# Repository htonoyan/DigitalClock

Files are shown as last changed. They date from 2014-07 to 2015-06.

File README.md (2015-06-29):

#Digital Clock
The "Hello World" project of any electrical engineer, a digital clock. This is a basic ATMegax8 design with the addition of linear constant current shift register sinks to switch low-power 7-segment LED displays that may need a voltage higher than the microcontroller supply voltage to work (I'm using 12V here).

You can read more about the project on my blog: http://htonoyan.blogspot.com. For any questions feel free to contact me by email or posting on the blog.

* Hardware/ Contains all the circuit board files (Altium Designer format, but a PDF version and gerbers are provided).
* Software/ Contains the code running on the AVR ATMega48. I used Atmel Studio with gcc to compile the code.

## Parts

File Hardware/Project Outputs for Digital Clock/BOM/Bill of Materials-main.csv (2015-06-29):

Designator | Supplier Part Number 1 | Description | Footprint | Quantity
BT1 | BU2032SM-HD-GDKR-ND | HOLDER COIN CELL 2032 SMD | BU2032SM-HD-G | 1
C1, C2 | 490-1403-1-ND | CAP CER 10PF 50V 5% C0G 0603 | 0603 | 2
C3, C5, C6, C9, C10 | 445-1316-1-ND | CAP CER .10UF 25V X7R 10% 0603 | 0603 | 5
C7, C8 | 338-1807-1-ND | CAP ALUM 220UF 25V 20% SMD | CAP AVE227M25F24T-F | 2
D1, D2 | 497-8030-6-ND | DIODE SCHOTTKY 30V 2A SMB | DSO-C2/X2.3 | 2
J1 | CP-036APJCT-ND | CONN PWR JACK 2.0X6.3MM SMT | CONN_PWR2.0_SMT | 1
J2, J3, J4, J5, J6, J7, J8, J9 | A19432-ND | CONN HEADER VERT 5POS .100 TIN | CONN_HDR1X5 | 8
P1 | WM17449-ND | Header, 3-Pin, Dual row | CONN_HDR_SMT_6_2R | 1
R1 | P4.70KHCT-ND | RES 4.70K OHM 1/10W 1% 0603 SMD | 0603 | 1
R2, R5 | P1.60KHDKR-ND | RES 1.60K OHM 1/10W 1% 0603 SMD | 0603 | 2
R3 | P698KHDKR-ND | RES 698K OHM 1/10W 1% 0603 SMD | 0603 | 1
R4 | P107KHCT-ND | RES 107K OHM 1/10W 1% 0603 SMD | 0603 | 1
S1, S2, S3, S4 | 506-1571634-2 | Single-Pole, Single-Throw Switch | 1571634-2 | 4
U1 | ATMEGA48V-10AU-ND | IC AVR MCU 4K 10MHZ 1.8V 32TQFP | 32A_N | 1
U2 | NCP1117DT33RKGOSCT-ND | IC REG LDO 3.3V DPAK | DPAK | 1
U3, U4 | 296-23916-1-ND | IC LED DRIVER LINEAR 24-QSOP | SOP24 | 2
U5 | TC1047AVNBCT-ND | IC TEMP-VOLT CONV PREC SOT-23B | SOT23-3N | 1
Y1 | 535-10241-1-ND | CRYSTAL 32.768 KHZ 6.0 PF SMD | ABS25 | 1

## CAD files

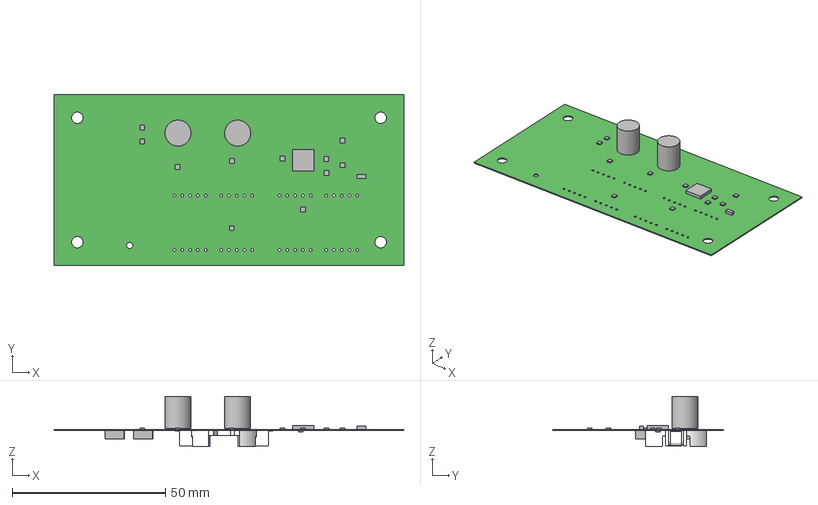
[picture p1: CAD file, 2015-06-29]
Hardware/Project Outputs for Digital Clock/ExportSTEP/PCB1_holes.step
114.3 x 55.9 x 16.5 mm
Board
Extruded x 18
BU2032SM-HD-GCR2032_Battery_Holder

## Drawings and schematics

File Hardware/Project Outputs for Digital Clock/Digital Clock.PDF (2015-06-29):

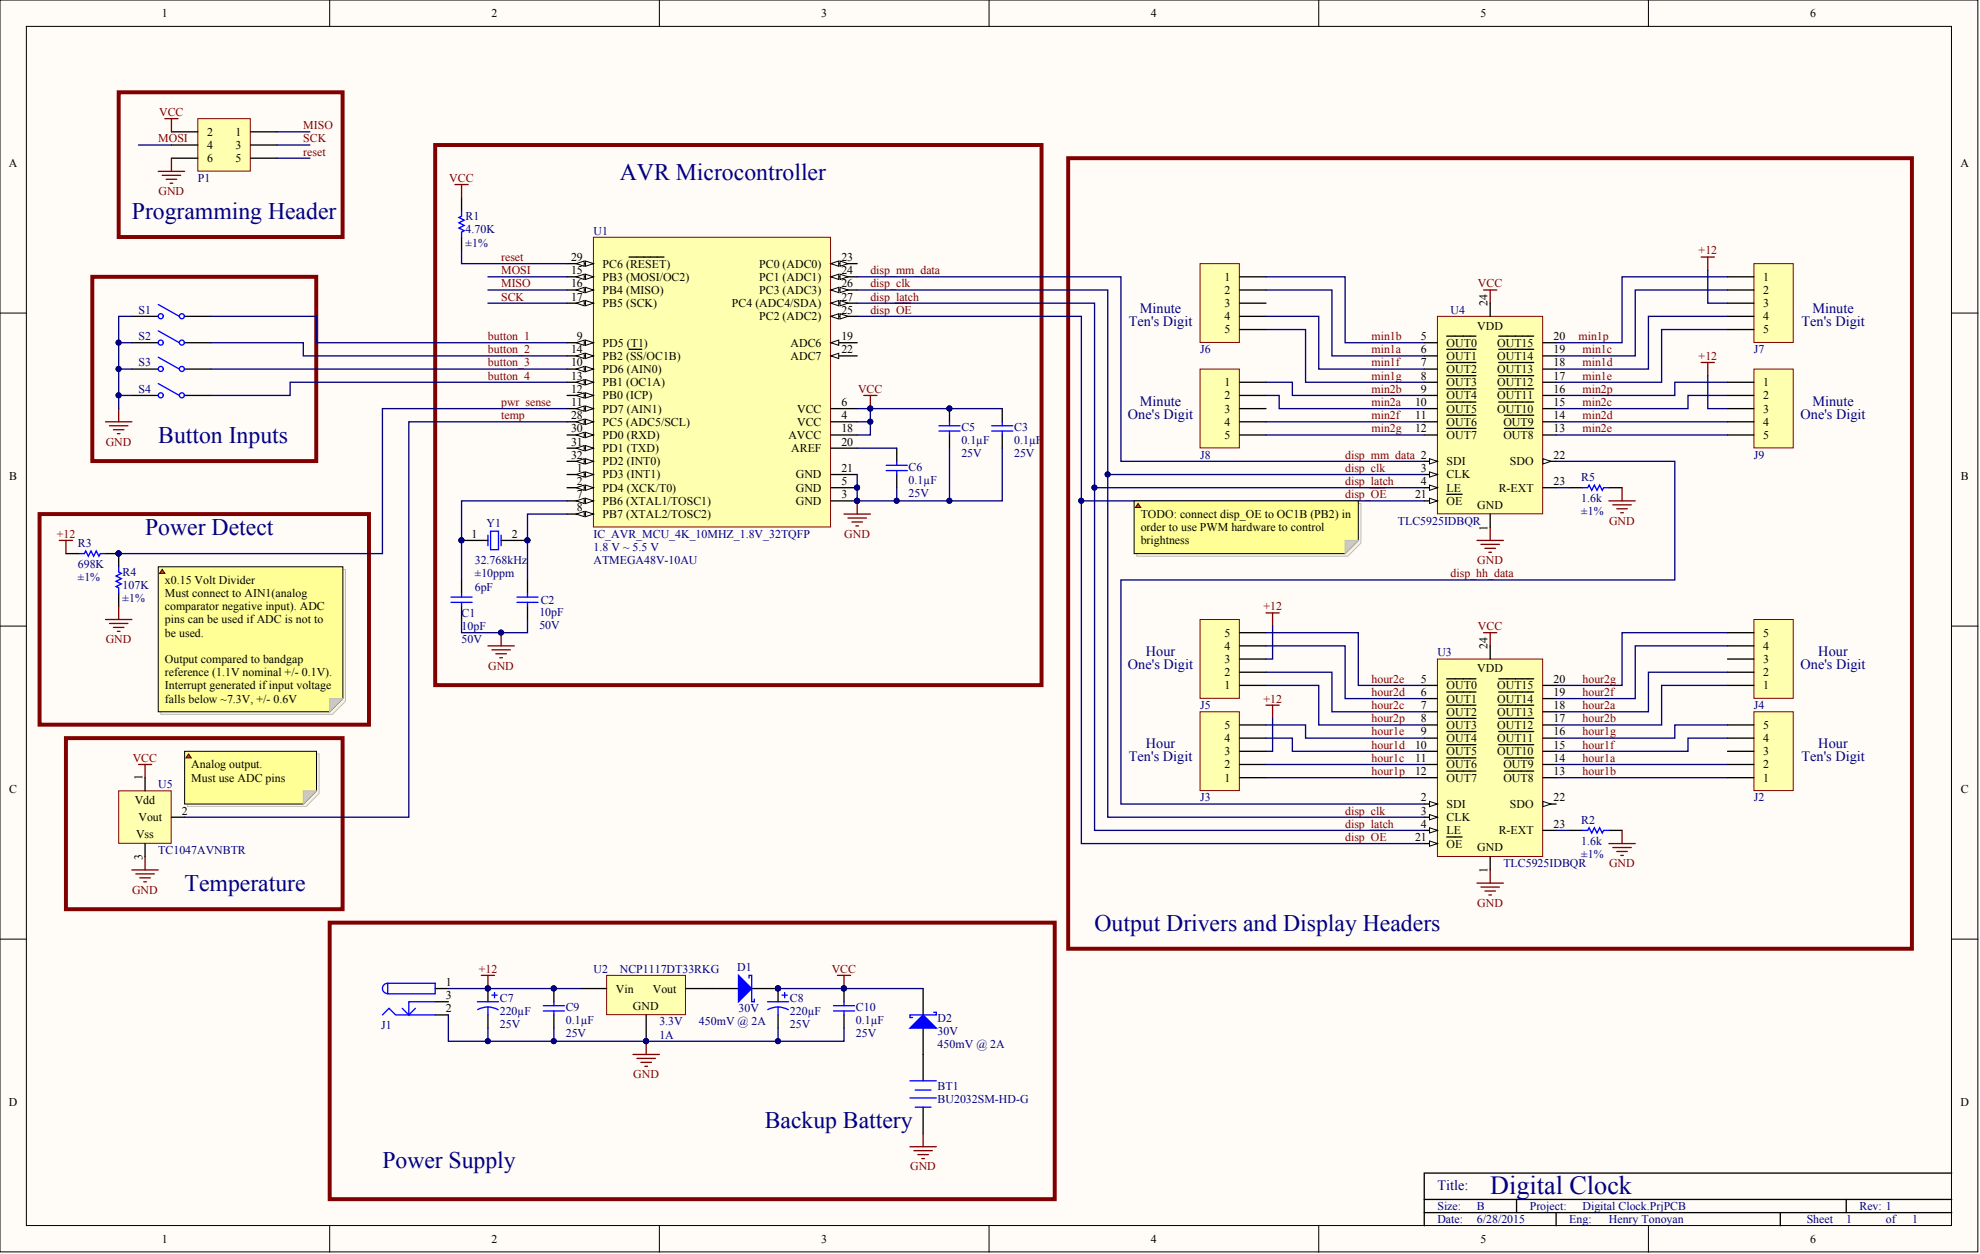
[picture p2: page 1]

1 | | | C6 | disp_clk | 3
2 | | 5 | 0.1 µ F | | disp_latch | 4
7 | | 3 | 25V | | | disp_OE | OE 21
8 | | | | TODO: connect disp_OE to OC1B (PB2) in order to use PWM hardware to control brightness

x0.15 Volt Divider
Must connect to AIN1(analog
comparator negative input). ADC
pins can be used if ADC is not to
be used.

Output compared to bandgap
reference (1.1V nominal +/- 0.1V).
Interrupt generated if input voltage
falls below ~7.3V, +/- 0.6V

hour2d | 6 | hour2f

hour1c | OUT6 11 | hour1a
hour1p | | hour1b

Analog output.
Must use ADC pins

Output Drivers and Display Headers

Size: B | Project: Digital Clock.PrjPCB | Rev: 1
Date: 6/28/2015 | Eng: Henry Tonoyan | Sheet 1 of 1

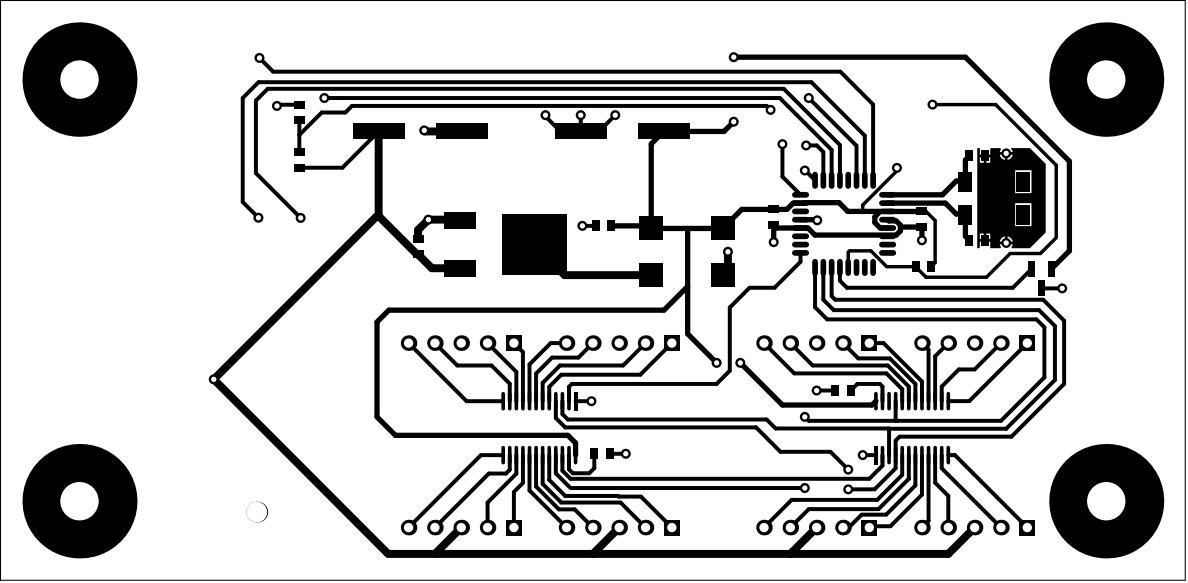
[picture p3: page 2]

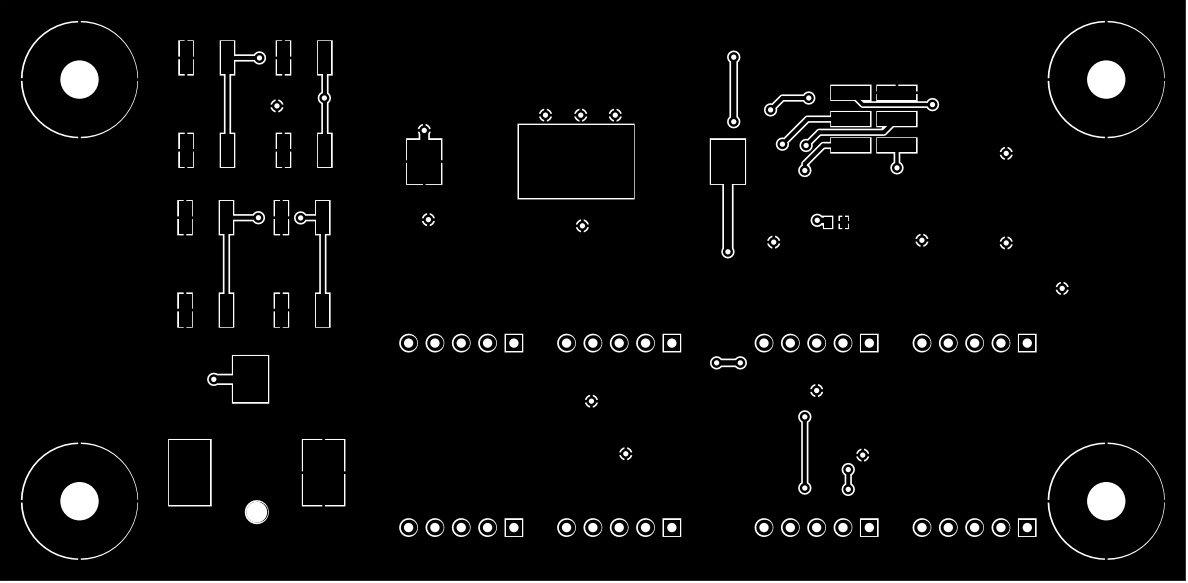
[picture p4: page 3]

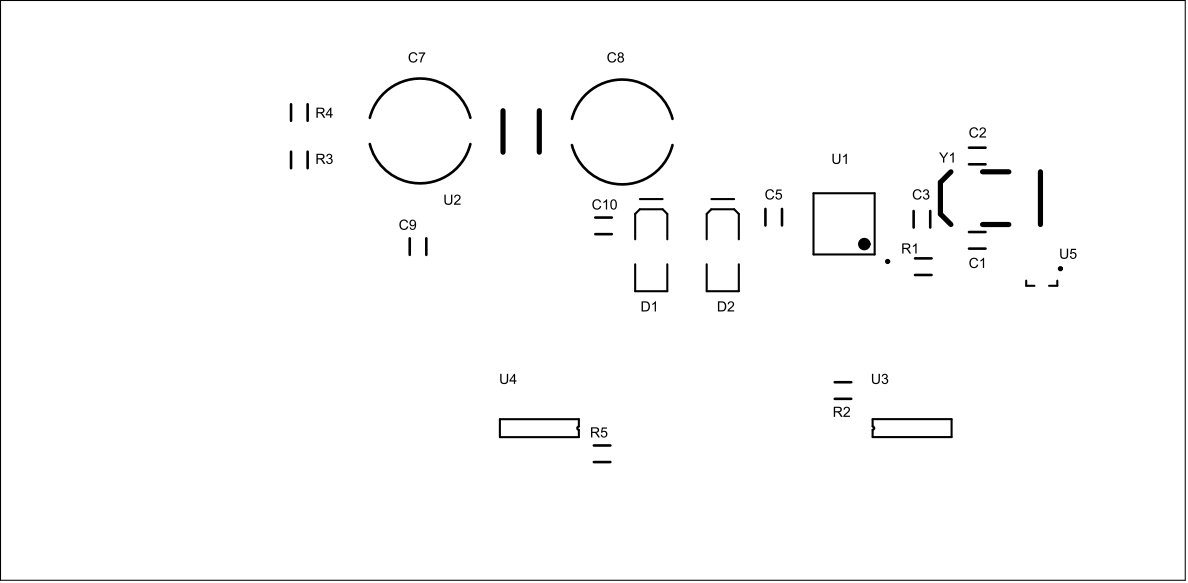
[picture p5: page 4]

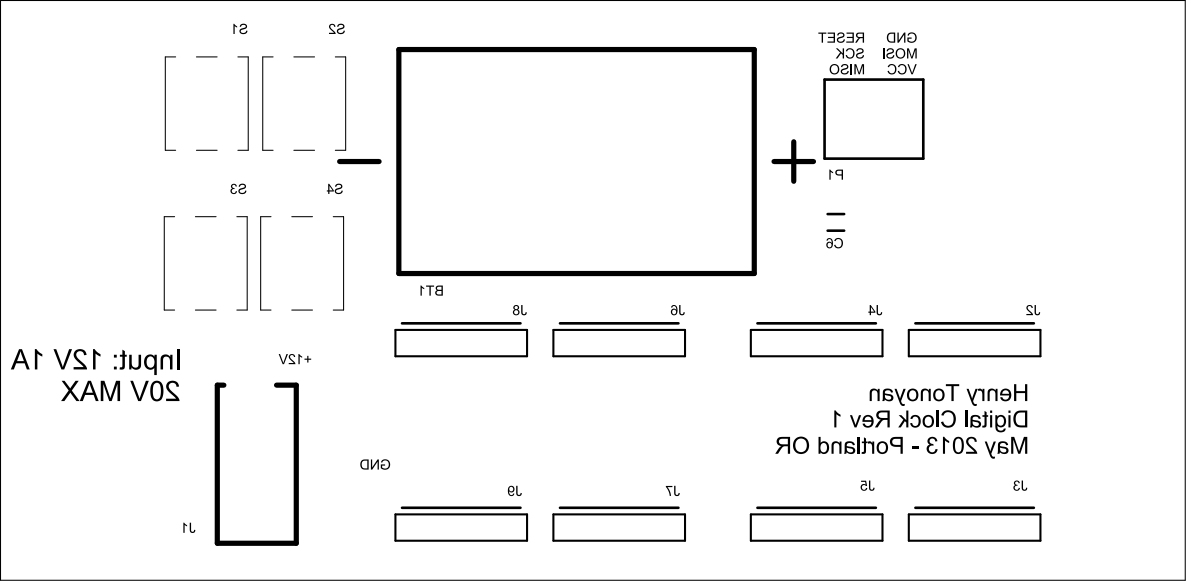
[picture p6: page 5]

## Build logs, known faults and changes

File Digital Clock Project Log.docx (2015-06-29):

Digital Clock Project Log

9/1/13

- Modification to PCB: swapping pins 25 & 14 to allow display_OE (output enable) to be controlled by PWM hardware module.

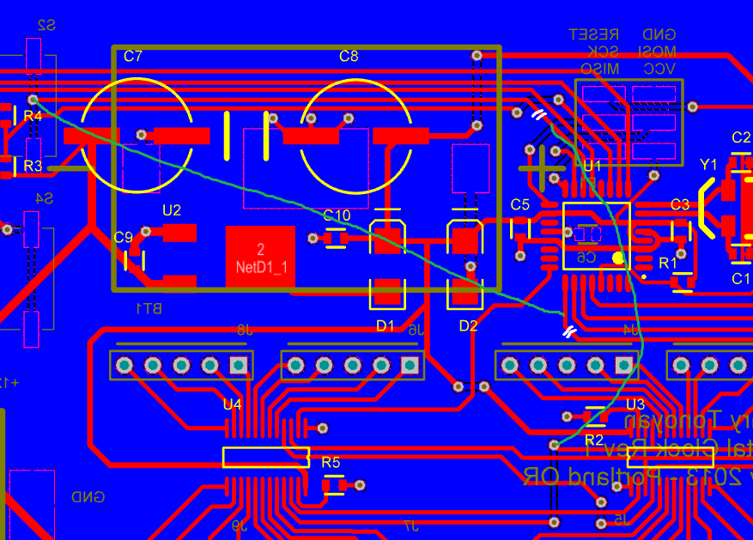
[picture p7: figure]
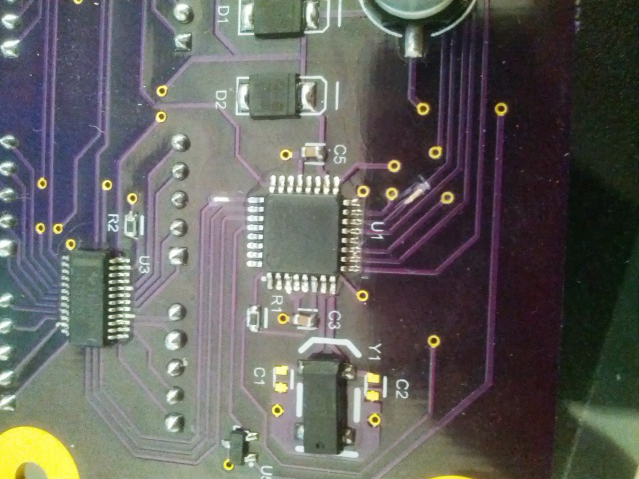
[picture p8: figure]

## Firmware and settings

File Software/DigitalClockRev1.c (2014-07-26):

#define F_CPU 1000000UL // 1 MHz
#include <avr/io.h>
#include <avr/interrupt.h>
#include <util/delay.h>
#include <avr/sleep.h>
#include "DigitalClockRev1.h"
#include "Display.h"

void initialize_display(void)
{
	//configure 16-bit timer register
//    Fast PWM Mode - TOP=OCR1A
//    Set OC1B on compare match, clear OC1B at BOTTOM
//    Clock: clk_I/O (no prescale)
    TCCR1A = _BV(COM1B1) | _BV(COM1B0) | _BV(WGM11) | _BV(WGM10);
    TCCR1B = _BV(WGM13) | _BV(WGM12) | _BV(CS10);
    OCR1A = 5000; // Reset PWM when counter reaches 5000, should be 200Hz.
    OCR1B = 2500;

	disp_OE_port &= ~_BV(disp_OE_bit); // enable display
}

void disable_display(void)
{
    TCCR1B &= ~_BV(CS12) & ~_BV(CS11) & ~_BV(CS10); // Set Timer1 clock source to none
    disp_OE_port |= _BV(disp_OE_bit); // disable display
}

void disable_buttons(void)
{
    PCICR = 0; // Button interrupts disabled
}

void enable_buttons(void)
{
    PCIFR |= _BV(PCIF0) | _BV(PCIF1) | _BV(PCIF2); // clear interrupt flags if they may have occurred
    PCICR = _BV(PCIE0) | _BV(PCIE1) | _BV(PCIE2);
}

void initialize_buttons(void)
{
	// configure external interrupts
    // B1 = Button 4 = PCINT1
    // C2 = Button 2 = PCINT10
    // D5 = Button 1 = PCINT21
    // D6 = Button 3 = PCINT22

    PCMSK0 = _BV(PCINT1);
    PCMSK1 = _BV(PCINT10);
    PCMSK2 = _BV(PCINT21) | _BV(PCINT22);
    PCICR = _BV(PCIE0) | _BV(PCIE1) | _BV(PCIE2);
}

void initialize(void)
{
	//configure IO
	DDRB = 0b00000100;
	DDRC = 0b00011010;
	DDRD = 0;

	PORTB = 0b11111111;
	PORTC = 0b01000101;
	PORTD = 0b01111111;

	//todo set power reduction register (PRR)

	//configure asynchronous timer registers
	TCCR2A = 0;
	TCCR2B = _BV(CS22) | _BV(CS20); // set prescaler to 128 (32,768 Hz / 128 = 256 counts / sec)
	TIMSK2 = _BV(TOIE2); // enable Timer/Counter2 Overflow interrupt (TOV2 bit set in TIFR2)
	ASSR = _BV(AS2); // clock Timer/Counter2 from a crystal Oscillator

	//configure analog comparator
    // Analog comparator multiplexer disabled (AIN1 applied to negative input)
    // AC bandgap selected (takes ~70us to stabilize)
    // AC interrupt enabled on output toggle
    ADCSRB = 0;
    ACSR = _BV(ACBG);
    DIDR1 = _BV(AIN1D); // Disable digital pin AIN1

    _delay_ms(1); // give time for analog voltage and timer to stabilize
    ACSR |= _BV(ACIE); // Enable AC interrupt
}

volatile uint8_t global_hours = 0;
volatile uint8_t global_minutes = 0;
volatile uint8_t global_seconds = 0;
volatile uint8_t known_time = 0;

// wake-up flags
volatile uint8_t button_pressed = 0;
volatile uint8_t second_passed = 0;
volatile uint8_t power_change = 0;

void handle_power(void)
{
    _delay_us(8); // wait to synchronize register with AC output
    if(!(ACSR & _BV(ACO)))
    {
        // We are plugged in
        initialize_display();
        enable_buttons();
    }
    else
    {
        // We are on battery power, turn off display and buttons
        disable_display();
        disable_buttons();
    }
}

void handle_button(void)
{
    disable_buttons();
    _delay_ms(10);

    if(!(button_1_pin&_BV(button_1_bit))) // Button 1 (Right-Up)
    {
        if(global_minutes != 59)
        {
            global_minutes++;
        }
        else
        {
            global_minutes = 0;
        }
        global_seconds = 0;
        TCNT2 = 0;
    }
    else if(!(button_3_pin&_BV(button_3_bit))) // Button 3 (Right-Down)
    {
        if(global_minutes != 0)
        {
            global_minutes--;
        }
        else
        {
            global_minutes = 59;
        }
        global_seconds = 0;
        TCNT2 = 0;
    }
    else if(!(button_2_pin&_BV(button_2_bit))) // Button 2 (Left-Up)
    {
        if(global_hours != 23)
        {
            global_hours++;
        }
        else
        {
            global_hours = 0;
        }
    }
    else if(!(button_4_pin&_BV(button_4_bit))) // Button 4 (Left-down)
    {
        if(global_hours != 0)
        {
            global_hours--;
        }
        else
        {
            global_hours = 23;
        }
    }
    enable_buttons();
    known_time = 1;
}

uint8_t hour_24h2ampm (uint8_t hour)
{
    if (hour == 0)
    {
        return 12;
    }
    else if(hour < 13)
    {
        return hour;
    }
    else
    {
        return hour-12;
    }
}

void increment_time(void)
{
	global_seconds++;
	if( global_seconds > 59 )
	{
		global_seconds = 0;
		global_minutes++;
	}
	if( global_minutes > 59 )
	{
		global_minutes = 0;
		global_hours++;
	}
	if( global_hours > 23 )
	{
		global_hours = 0;
    }

    // Dim during night hours
    if( global_hours < 5 || global_hours > 21 )
    {
        OCR1B = 500;
    }
    else
    {
        OCR1B = 5000;
    }
 // if the time is reset, flash display
    if((known_time == 0) && (global_seconds % 2))
    {
        OCR1B = 1;
    }
}

int main(void)
{
	initialize();

    sei();
    if(!(ACSR & _BV(ACO)))
    {
        // We are plugged in
        initialize_display();
        initialize_buttons();
        set_sleep_mode(SLEEP_MODE_IDLE);
        sleep_mode();
    }
    else
    {
        // We are on battery power, go to sleep without display or buttons
        set_sleep_mode(SLEEP_MODE_PWR_SAVE);
        sleep_mode();
    }
    initialize_display();
    initialize_buttons();
    set_sleep_mode(SLEEP_MODE_IDLE);
    sleep_mode();

	while(1)
    {
        // something woke us up
        if(second_passed)
        {
            increment_time();
            second_passed = 0;
        }
        if(button_pressed)
        {
            handle_button();
            button_pressed = 0;
        }
        if(power_change)
        {
            handle_power();
            power_change = 0;
        }
        
        if(!(ACSR & _BV(ACO)))
        {
            // plugged in
            updateDisplay( hour_24h2ampm(global_hours), global_minutes );
            set_sleep_mode(SLEEP_MODE_IDLE);
            sleep_mode();
        }
        else
        {
            set_sleep_mode(SLEEP_MODE_PWR_SAVE);
            sleep_mode();
        }
    }
	return 0;
}

ISR(ANALOG_COMP_vect)
{
    power_change = 1;
}

ISR(TIMER2_OVF_vect)
{
    second_passed = 1;
}

ISR(PCINT0_vect)
{
    button_pressed = 1;
}

ISR(PCINT1_vect)
{
    button_pressed = 1;
}

ISR(PCINT2_vect)
{
    button_pressed = 1;
}

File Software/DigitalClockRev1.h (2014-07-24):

#define disp_data_port PORTC
#define disp_data_bit 1

#define disp_OE_port PORTB
#define disp_OE_bit 2

#define disp_clk_port PORTC
#define disp_clk_bit 3

#define disp_latch_port PORTC
#define disp_latch_bit 4

#define temperature_port PORTC
#define temperature_bit 5

#define button_1_port PORTD
#define button_1_pin PIND
#define button_1_bit 5

#define button_3_port PORTD
#define button_3_pin PIND
#define button_3_bit 6

#define button_4_port PORTB
#define button_4_pin PINB
#define button_4_bit 1

#define button_2_port PORTC
#define button_2_pin PINC
#define button_2_bit 2

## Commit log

2013-09-03 Swap disp_OE and button_2 pins
    [DigitalClockRev1.c, DigitalClockRev1.h]
2014-07-20 Basic button input for min/hour adjust. Needs debouncing.
2014-07-21 Time adjustment, button debouncing works better now.
2014-07-21 Auto-dimming works properly. Display flashes when time reset.
    [DigitalClockRev1.c]
2014-07-24 Working buttons, power-off detection, and sleep modes.
2014-07-26 Fixed 24h bug, switched to displaying ampm.
    [DigitalClockRev1.c]
2015-06-29 Add hardware files to repository.
    Software files moved to subfolder /Software/
    Hardware files added to subfolder /Hardware/
    [Bill of Materials-main.csv, Digital Clock.PrjPCB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]
2015-06-29 Clean up schematic, add PDF version of project
    [Digital Clock.PrjPCB, PCB1.PcbDoc, main.SchDoc]
